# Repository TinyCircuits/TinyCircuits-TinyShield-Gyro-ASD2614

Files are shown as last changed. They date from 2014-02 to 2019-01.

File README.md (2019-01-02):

# TinyCircuits TinyShield Gyro Board
# ASD2614 Rev1

These design files are located under design_files/ for the TinyCircuits ASD2614 Rev 1 PCB.  This is a TinyShield board (Square Version, 20mm x 20mm, or Circular 20mm diameter) that has a ST L3G4200D Gyroscope, local power supply and level shifters to connect between the TinyDuino and the accelerometer. 

Format is in Cadsoft Eagle format - Eagle version 6.2 was used for the original design.

For more infomation on this, check out the product page at TinyCircuits.com:  https://tinycircuits.com/collections/sensors/products/gyroscope-tinyshield

#License:

Design by TinyCircuits.
All design files are released under the Creative Commons Attribution Share-Alike 3.0 License, see the following link for details: http://creativecommons.org/licenses/by-sa/3.0

All text above must be included in any redistribution or derived design

This project uses designs and concepts developed as part of the Arduino project and the LilyPad project.  The TinyCircuits design files themselves (schematics, PCB and libraries) are not directly derived from these works' design files and have been created new, however the concepts and basic architecture behind the TinyDuino and TinyLily products are derived and we thank the hard work of the organizations below for their contributions to open-source hardware:
  
Original Arduino Uno Design by Team Arduino

LilyPad Arduino Design by Leah Buechley and Sparkfun Electronics

Please support the open-source hardware community

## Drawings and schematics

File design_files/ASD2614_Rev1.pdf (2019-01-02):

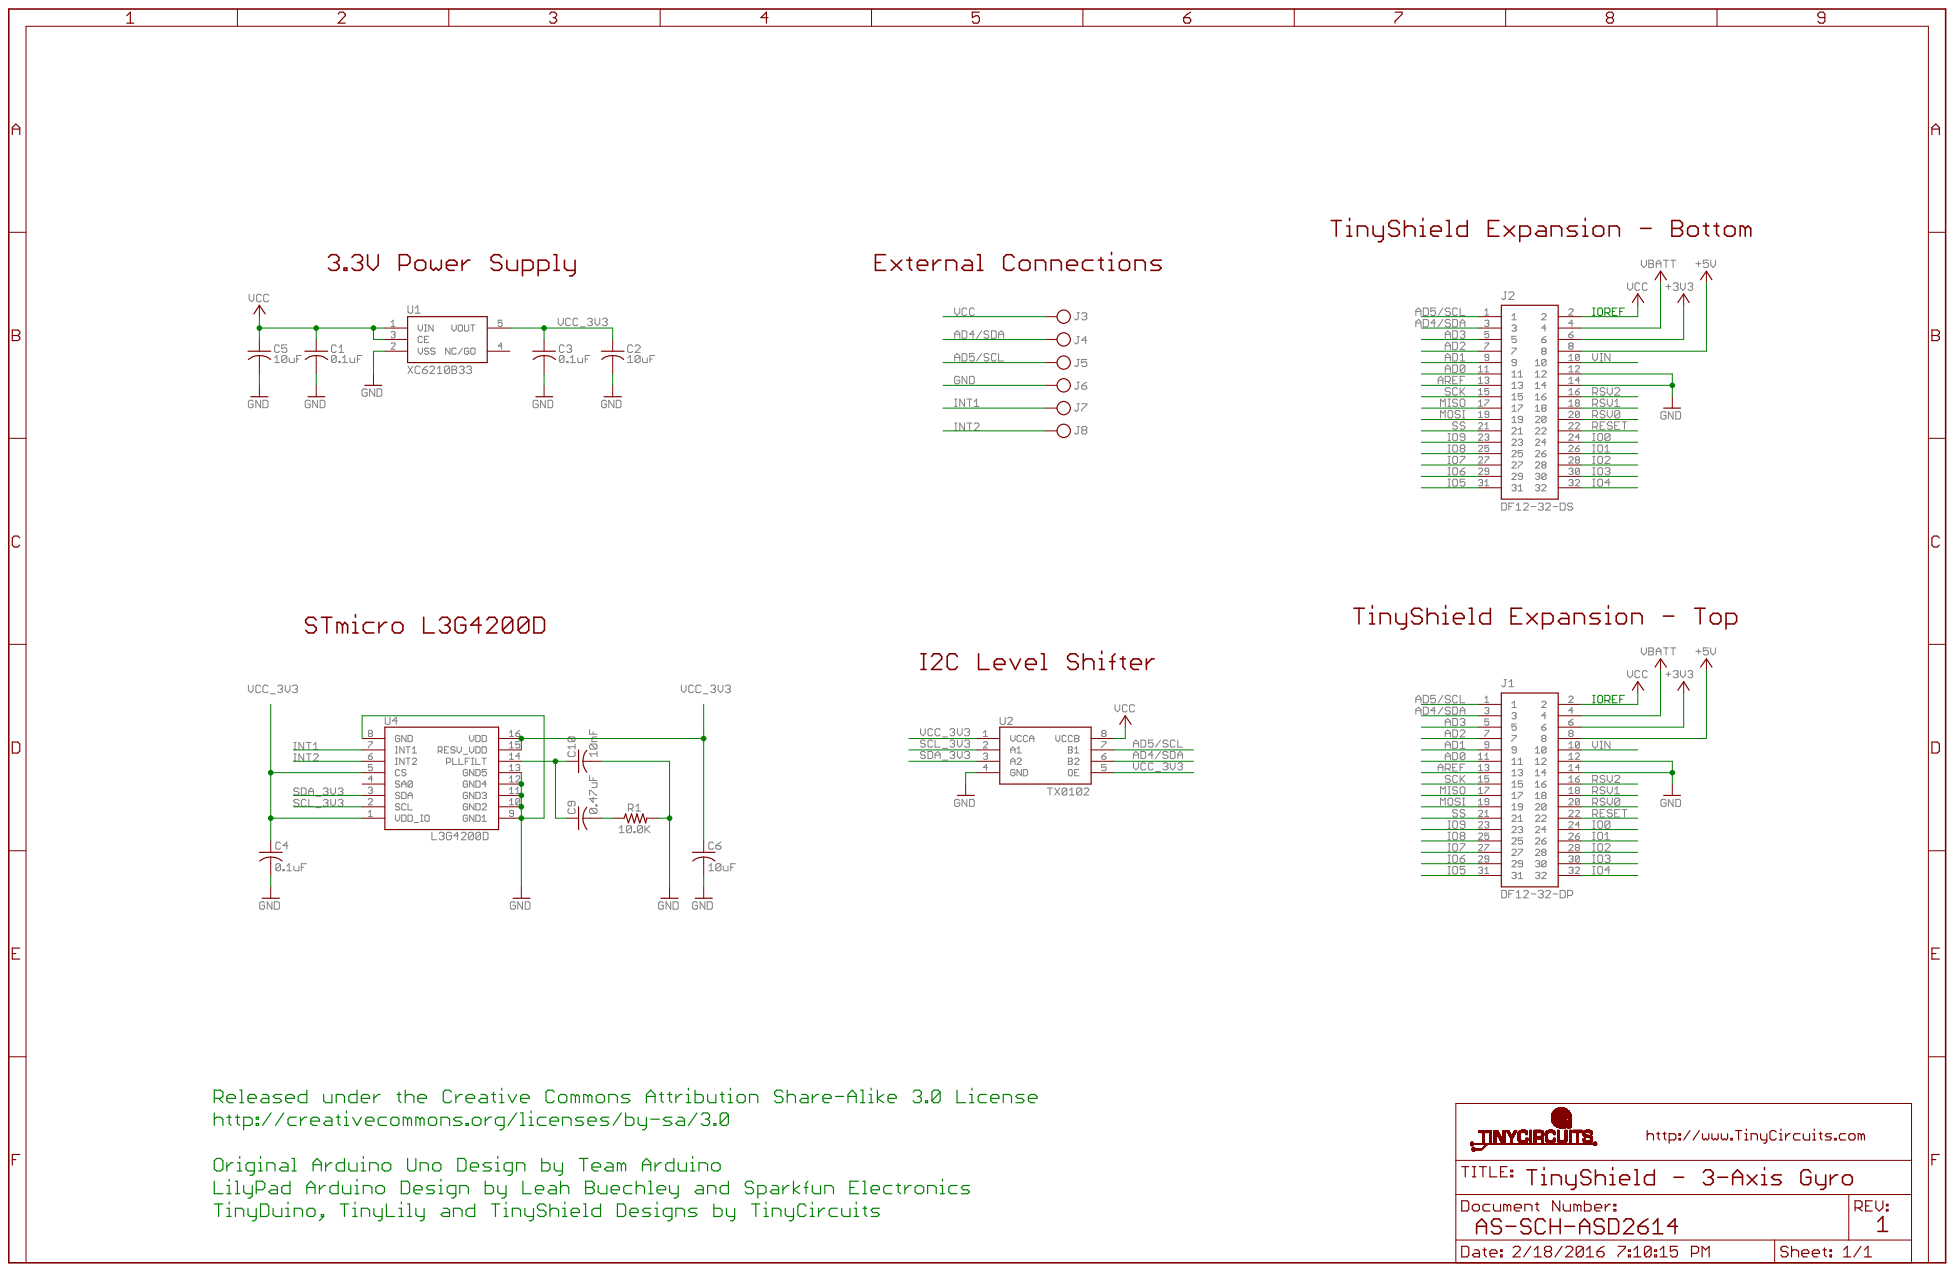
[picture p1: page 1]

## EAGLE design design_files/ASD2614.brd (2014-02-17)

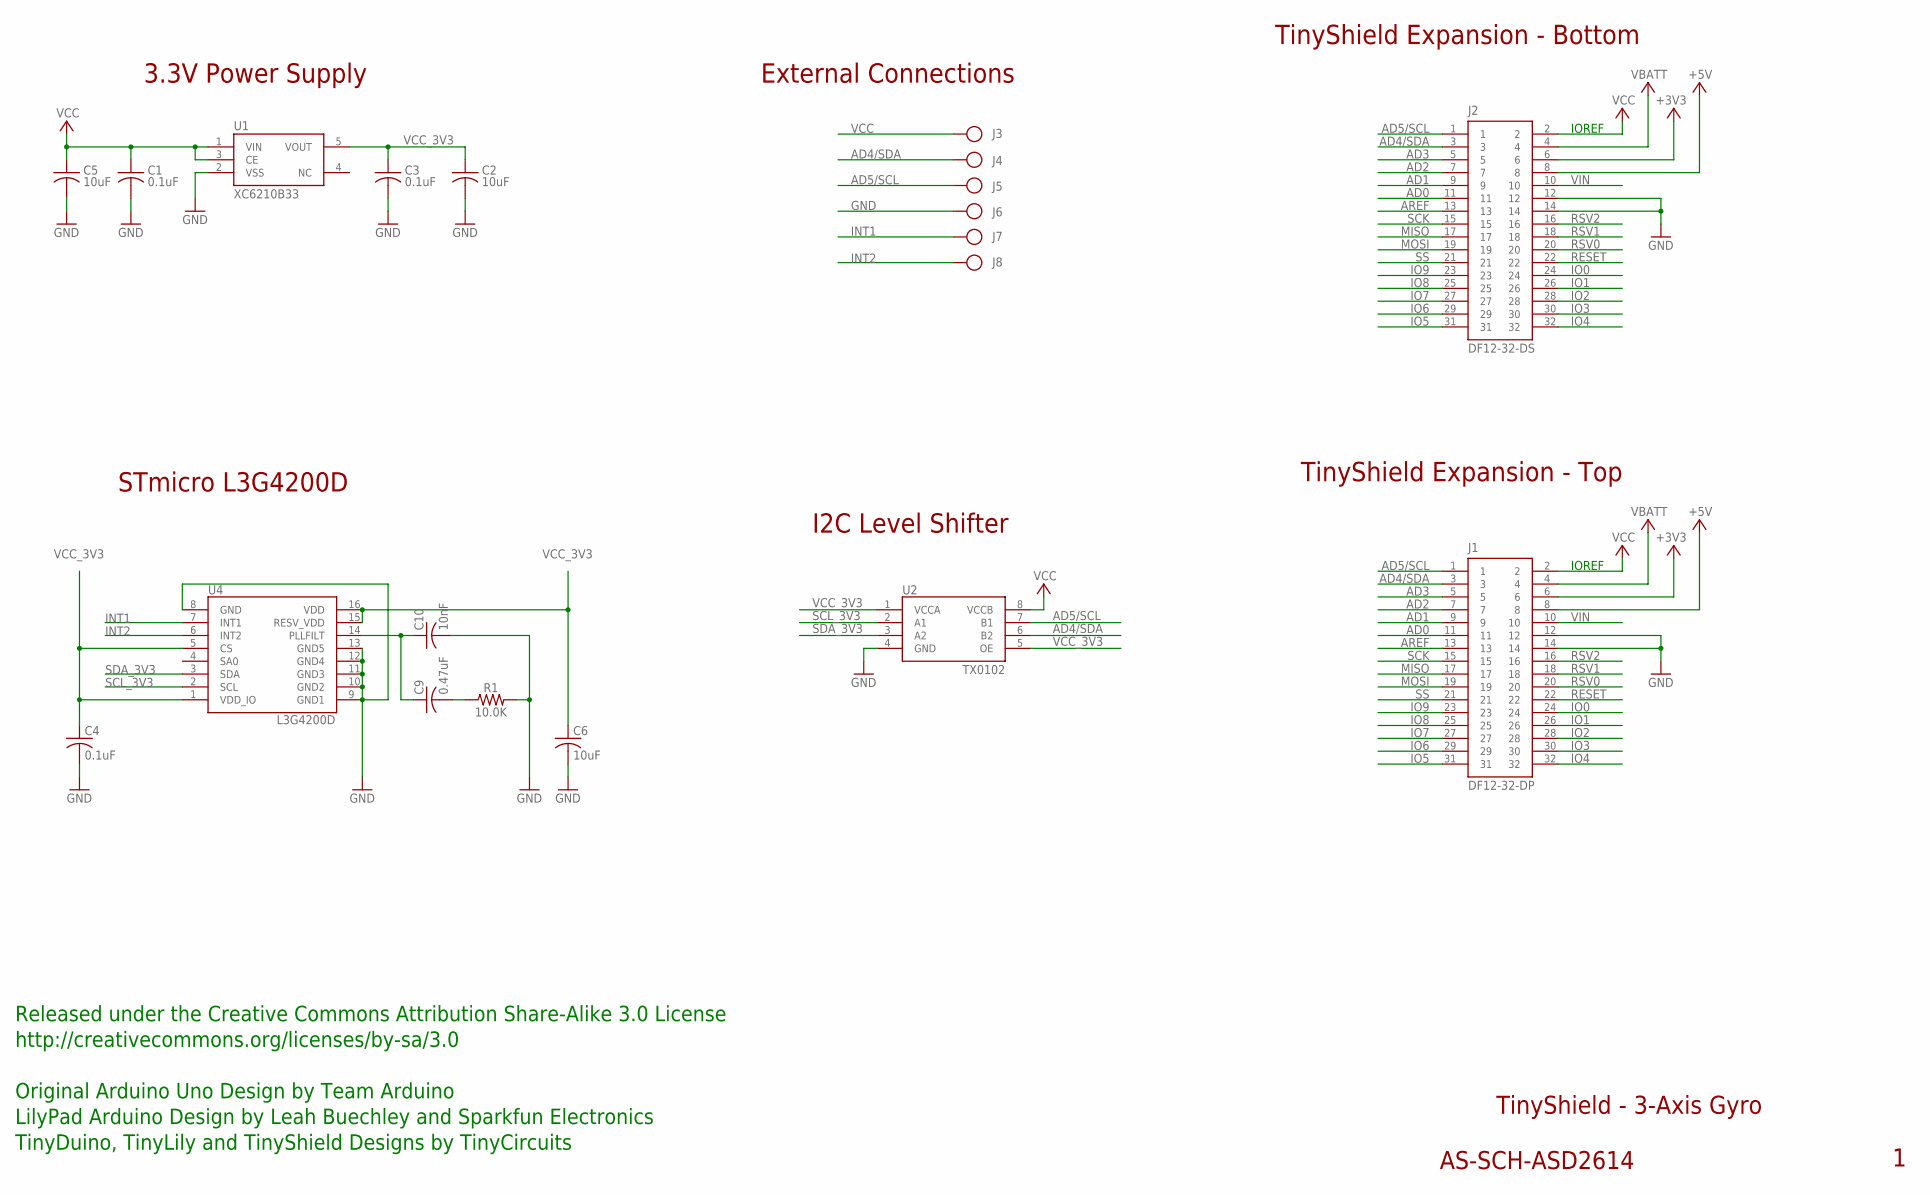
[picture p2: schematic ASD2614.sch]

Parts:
C1, C3: 0.1uF; C0402; PARTNO AS-ITM-00008
C2: 10uF; C0805; PARTNO AS-ITM-00045
C4: 0.1uF; C0402
C5: 10uF; C0805
C6: 10uF; C0603
C9: 0.47uF; C0402
C10: 10nF; 0402
J1: DF12-32-DP; PARTNO AS-ITM-00015
J2: DF12-32-DS; PARTNO AS-ITM-00012
J3, J4, J5, J6, J7, J8: PIN_1X.1"; 1X.1"
R1: 10.0K; 0402
U1: XC6210B33; SOT-25
U2: TX0102; DQE(R-PX2SON-N8)
U4: L3G4200D

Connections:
+3V3: J1.6, J2.6
+5V: J1.8, J2.8
AD0: J1.11, J2.11
AD1: J1.9, J2.9
AD2: J1.7, J2.7
AD3: J1.5, J2.5
AD4/SDA: J1.3, J2.3, J4.1, U2.6 (B2)
AD5/SCL: J1.1, J2.1, J5.1, U2.7 (B1)
AREF: J1.13, J2.13
GND: C1.2, C2.2, C3.2, C4.2, C5.2, C6.2, C10.2, J1.12, J1.14, J2.12, J2.14, J6.1, R1.2, U1.2 (VSS), U2.4 (GND), U4.8 (GND), U4.9 (GND1), U4.10 (GND2), U4.11 (GND3), U4.12 (GND4), U4.13 (GND5)
INT1: J7.1, U4.7 (INT1)
INT2: J8.1, U4.6 (INT2)
IO0: J1.24, J2.24
IO1: J1.26, J2.26
IO2: J1.28, J2.28
IO3: J1.30, J2.30
IO4: J1.32, J2.32
IO5: J1.31, J2.31
IO6: J1.29, J2.29
IO7: J1.27, J2.27
IO8: J1.25, J2.25
IO9: J1.23, J2.23
MISO: J1.17, J2.17
MOSI: J1.19, J2.19
unnamed: C9.2, R1.1
unnamed: C9.1, C10.1, U4.14 (PLLFILT)
RESET: J1.22, J2.22
RSV0: J1.20, J2.20
RSV1: J1.18, J2.18
RSV2: J1.16, J2.16
SCK: J1.15, J2.15
SCL_3V3: U2.2 (A1), U4.2 (SCL)
SDA_3V3: U2.3 (A2), U4.3 (SDA)
SS: J1.21, J2.21
VBATT: J1.4, J2.4
VCC: C1.1, C5.1, J1.2, J2.2, J3.1, U1.1 (VIN), U1.3 (CE), U2.8 (VCCB)
VCC_3V3: C2.1, C3.1, C4.1, C6.1, U1.5 (VOUT), U2.1 (VCCA), U2.5 (OE), U4.1 (VDD_IO), U4.5 (CS), U4.15 (RESV_VDD), U4.16 (VDD)
VIN: J1.10, J2.10

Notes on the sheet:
TinyShield Expansion - Bottom
TinyShield - 3-Axis Gyro
AS-SCH-ASD2614
TinyShield Expansion - Top
IOREF
Released under the Creative Commons Attribution Share-Alike 3.0 License
http://creativecommons.org/licenses/by-sa/3.0
LilyPad Arduino Design by Leah Buechley and Sparkfun Electronics
TinyDuino, TinyLily and TinyShield Designs by TinyCircuits
Original Arduino Uno Design by Team Arduino
External Connections
3.3V Power Supply
I2C Level Shifter
STmicro L3G4200D

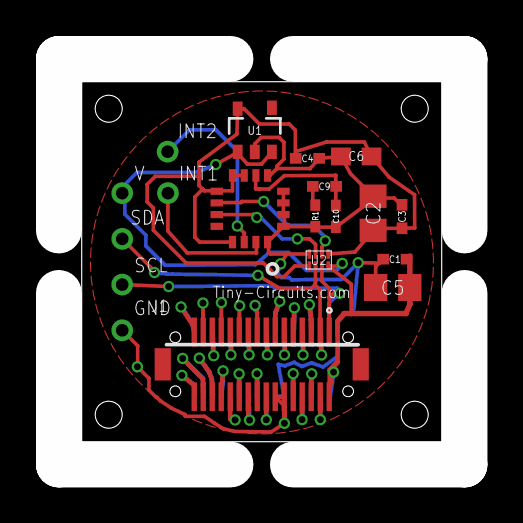
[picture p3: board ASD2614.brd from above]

Board: 2 copper layers, 20.0 x 20.0 mm, 21 parts (1 on the bottom side), 38 nets.

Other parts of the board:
U$1: DOCFIELD-TINYCIRCUITS-PCB

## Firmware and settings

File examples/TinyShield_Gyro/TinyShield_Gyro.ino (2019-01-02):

/* LucidTronix L3G4200D Gyroscope Library
 * For instructions, details and schematic, See:
 * http://www.lucidtronix.com/tutorials/63
 */
 
#include "L3G4200D.h"
#include "Wire.h"

L3G4200D gyro;

int x, y, z;

void setup(){
  Wire.begin();
  gyro.initialize(2000);
  Serial.begin(9600);
}

void loop(){
  x = gyro.getX();
  Serial.print("X:");
  Serial.print(x);

  y = gyro.getY();
  Serial.print(" Y:");
  Serial.print(y);

  z = gyro.getZ();
  Serial.print(" Z:");
  Serial.println(z);
  delay(300); //Just here to slow down the serial to make it more readable
}

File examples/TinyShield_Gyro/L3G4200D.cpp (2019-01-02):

#if defined(ARDUINO) && ARDUINO >= 100
#include "Arduino.h"
#else
#include "WProgram.h"
#endif

#include "L3G4200D.h"
#include <Wire.h>

#define CTRL_REG1 0x20
#define CTRL_REG2 0x21
#define CTRL_REG3 0x22
#define CTRL_REG4 0x23
#define CTRL_REG5 0x24



L3G4200D :: L3G4200D(){
  L3G4200D_Address = 105; //I2C address of the L3G4200D
}

int L3G4200D :: getX(){
  byte xMSB = readRegister(L3G4200D_Address, 0x29);
  byte xLSB = readRegister(L3G4200D_Address, 0x28);
  return ((xMSB << 8) | xLSB);
}

int L3G4200D :: getY(){
  byte yMSB = readRegister(L3G4200D_Address, 0x2B);
  byte yLSB = readRegister(L3G4200D_Address, 0x2A);
  return ((yMSB << 8) | yLSB);
}

int L3G4200D :: getZ(){
  byte zMSB = readRegister(L3G4200D_Address, 0x2D);
  byte zLSB = readRegister(L3G4200D_Address, 0x2C);
  return ((zMSB << 8) | zLSB);
}

void L3G4200D :: initialize(int scale){
  //From  Jim Lindblom of Sparkfun's code

  // Enable x, y, z and turn off power down:
  writeRegister(L3G4200D_Address, CTRL_REG1, 0b00001111);

  // If you'd like to adjust/use the HPF, you can edit the line below to configure CTRL_REG2:
  writeRegister(L3G4200D_Address, CTRL_REG2, 0b00000000);

  // Configure CTRL_REG3 to generate data ready interrupt on INT2
  // No interrupts used on INT1, if you'd like to configure INT1
  // or INT2 otherwise, consult the datasheet:
  writeRegister(L3G4200D_Address, CTRL_REG3, 0b00001000);

  // CTRL_REG4 controls the full-scale range, among other things:

  if(scale == 250){
    writeRegister(L3G4200D_Address, CTRL_REG4, 0b00000000);
  }else if(scale == 500){
    writeRegister(L3G4200D_Address, CTRL_REG4, 0b00010000);
  }else{
    writeRegister(L3G4200D_Address, CTRL_REG4, 0b00110000);
  }

  // CTRL_REG5 controls high-pass filtering of outputs, use it
  // if you'd like:
  writeRegister(L3G4200D_Address, CTRL_REG5, 0b00000000);
}

void L3G4200D :: writeRegister(int deviceAddress, byte address, byte val) {
    Wire.beginTransmission(deviceAddress); // start transmission to device 
    Wire.write(address);       // send register address
    Wire.write(val);         // send value to write
    Wire.endTransmission();     // end transmission
}

int L3G4200D :: readRegister(int deviceAddress, byte address){

    int v;
    Wire.beginTransmission(deviceAddress);
    Wire.write(address); // register to read
    Wire.endTransmission();

    Wire.requestFrom(deviceAddress, 1); // read a byte

    while(!Wire.available()) {
        // waiting
    }

    v = Wire.read();
    return v;
}
